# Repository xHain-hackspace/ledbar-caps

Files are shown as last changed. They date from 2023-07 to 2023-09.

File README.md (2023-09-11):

# ledbar-caps
Protective/supporting caps for creating triangle-based structures using our LED bars and rope.

For camp 2023 we wanted to build a structure using LED bars based on pipes we already have and rope running on the inside of the pipes. 3 pipes will be assembled to form  triangle and the triangles will be assembled to create shapes. For this, the ends of the pipes need a proper load bearing area and also some protection for the cables running on the outside. This repo contains 3D printable end caps which will hopefully do that job.

## Design/Test Notes
## 'cap_v4' Design
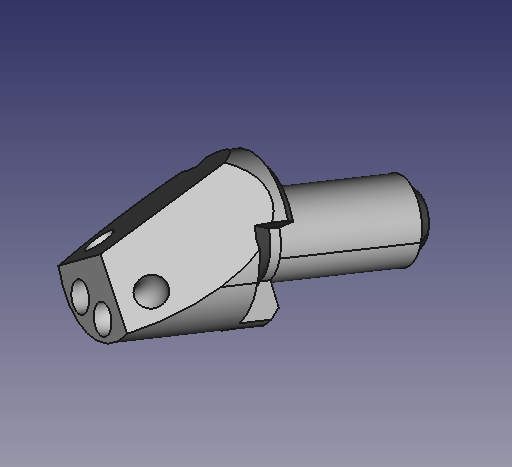
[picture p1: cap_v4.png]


  - WIP, the version we are currently testing/improving
## 'cap_v3' Design
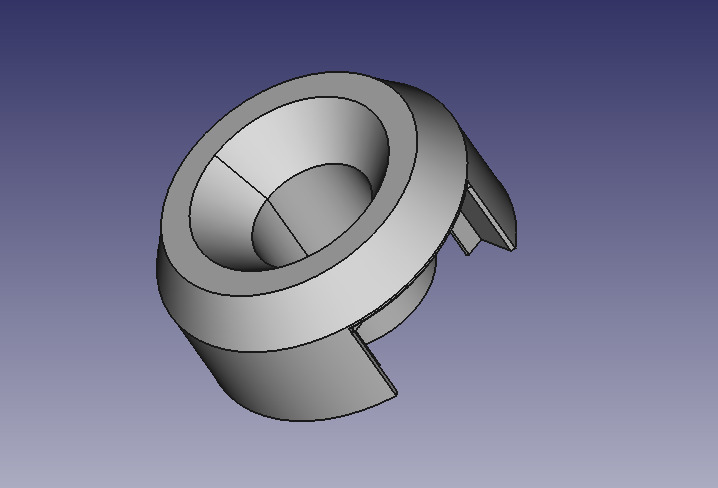
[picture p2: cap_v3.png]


  - the version we used for CCCamp in the end
  - changed top side from round to 30° edge as else the rope and the round cap create a turning moment that pulls out the caps
  - this fixes that round cap makes rope too far off pivot point, so cap wants to twist out of pipe
  - also makes everything a bit more stable (line load vs. point load)
  - threading rope works OK, a bit fiddly for multi-rope pipes
  - still kind of fiddly to set up with all the rope threading, but worked OK
  - still very sturdy with 60% infill
  - prints completely without supports
## 'cap_v2' Design
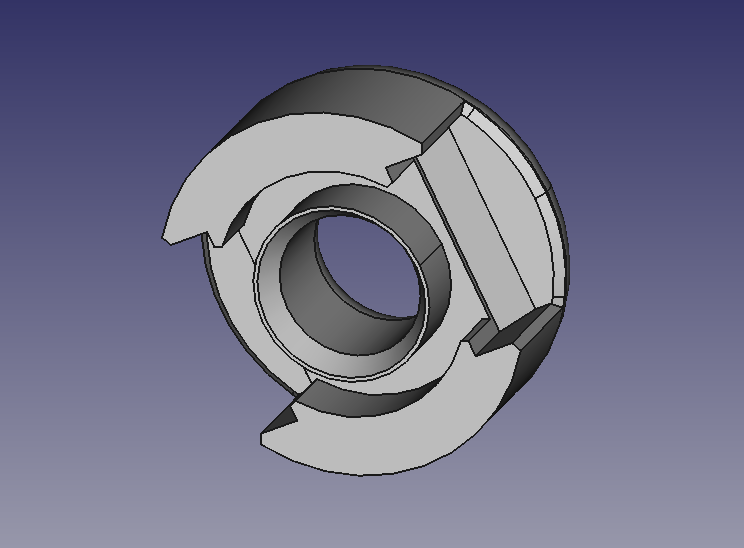
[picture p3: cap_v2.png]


  - chamfers make cap nicer and more cable friendly
  - round cap makes rope too far off pivot point, so cap wants to twist out of pipe
  - 'cap' design would probably also have this problem when tested with rope
  - inner diameter looks good
  - chamfer on inner hole makes first layer hard to print and stick for middle portion (single line circle)
  - threading rope seems to work nicely
  - still sturdy middle portion (100% infill)
## 'cap' Design
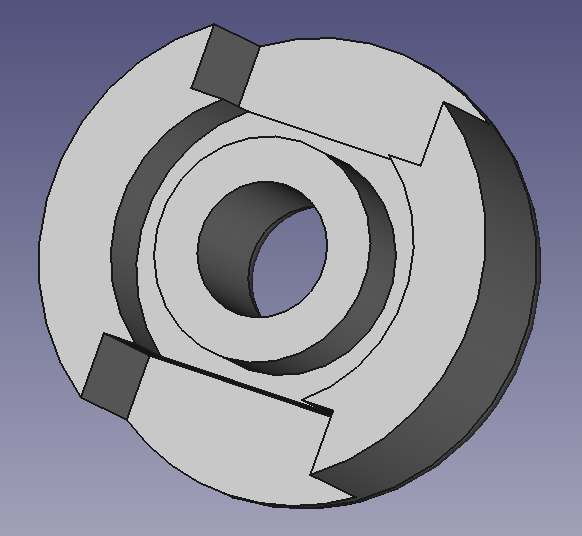
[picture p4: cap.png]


  - sits well on pipe
  - cable protection ok but, sharp edges should be chamfered
  - needs support, but we might be able to drop this
  - hole in middle needs to be bigger
  - threading rope might be difficult because of edge, might need chamfer on the inside

## 'goldcap' Design
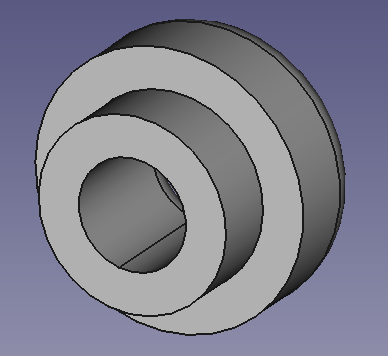
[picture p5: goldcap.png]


  - currently too small inside plug (radius/diameter mixup by accident)
  - does not really protect cables, needs to be longer
  - prints faster
  - needs support
  - hole in middle needs to be bigger
  - threading rope might be difficult because of edge, might need chamfer on the inside

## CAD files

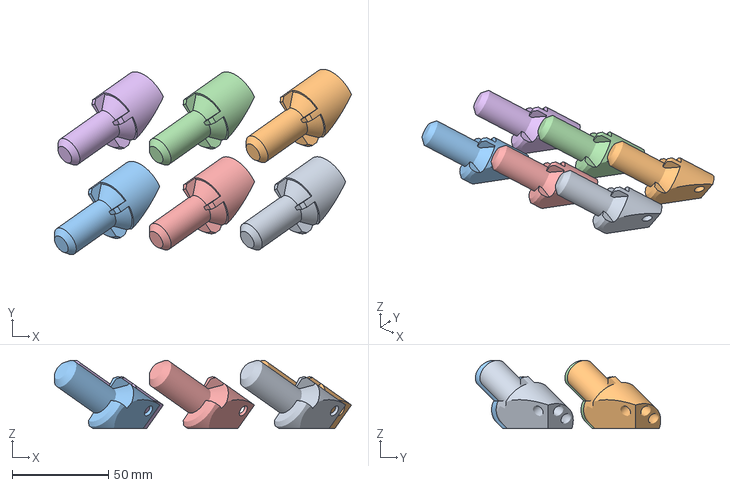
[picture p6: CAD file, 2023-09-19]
cap_v4-Body_6x_brim.3mf
154.1 x 96.2 x 35.4 mm
cap_v4-Body x 6

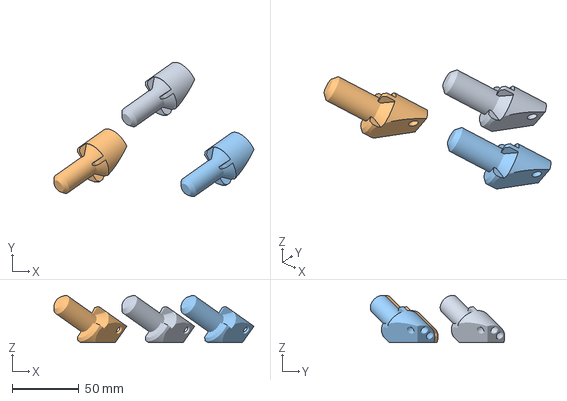
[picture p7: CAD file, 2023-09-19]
cap_v4-Body_3x_brim.3mf
150.0 x 100.9 x 35.4 mm
cap_v4-Body x 3

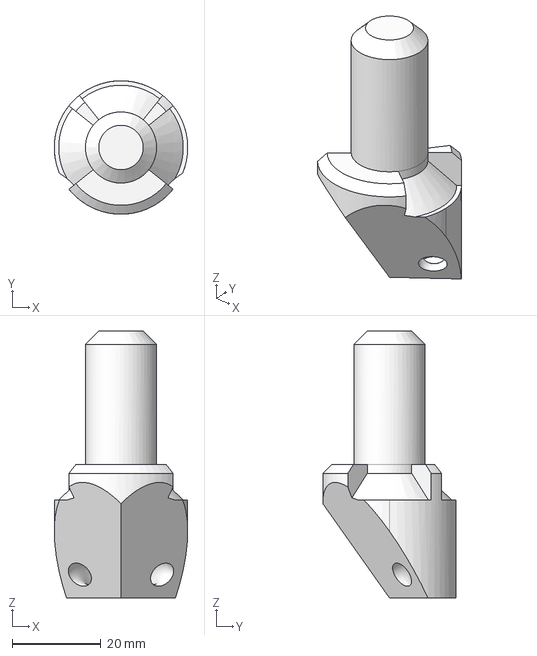
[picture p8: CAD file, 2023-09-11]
cap_v4-Body.step
30.0 x 30.0 x 60.0 mm

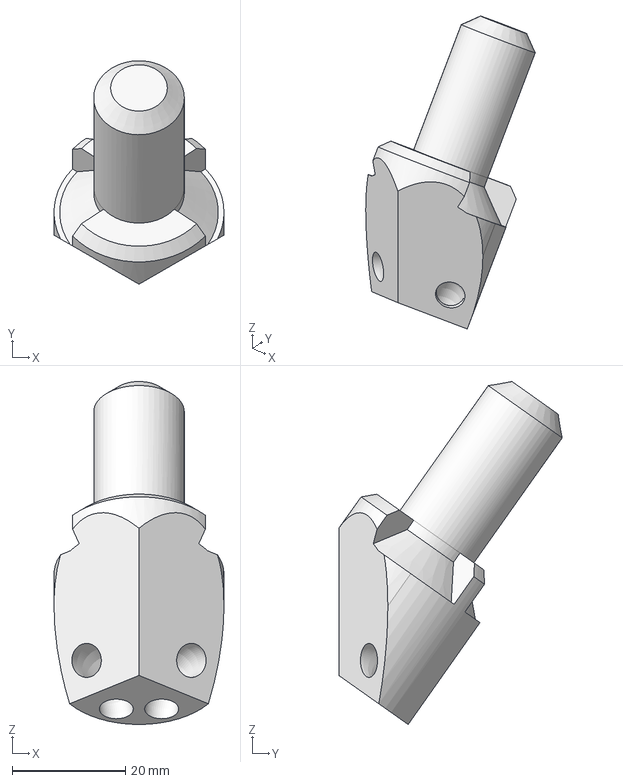
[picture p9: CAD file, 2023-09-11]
cap_v4.FCStd
30.0 x 39.4 x 60.5 mm

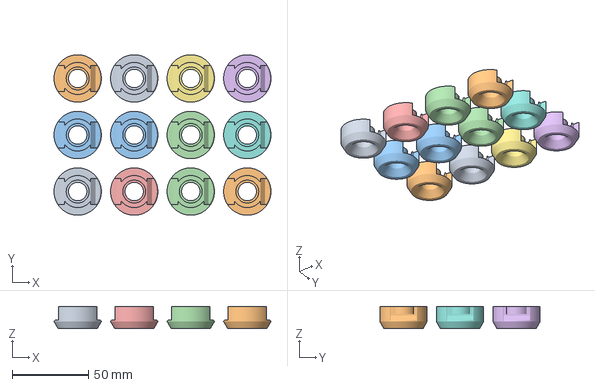
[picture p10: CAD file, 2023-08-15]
cap_v3-Body_fast_12x.3mf
142.0 x 105.0 x 14.7 mm
cap_v3-Body x 12

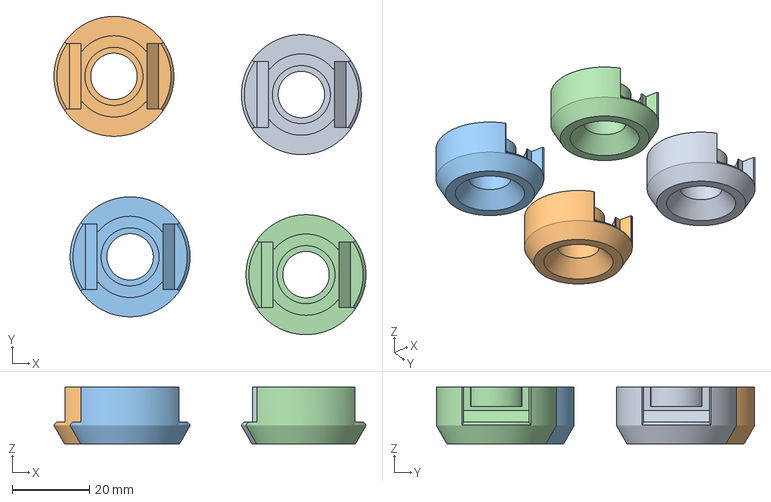
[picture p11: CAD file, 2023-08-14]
cap_v3-Body_fast_4x.3mf
80.6 x 82.3 x 14.7 mm
cap_v3-Body x 4

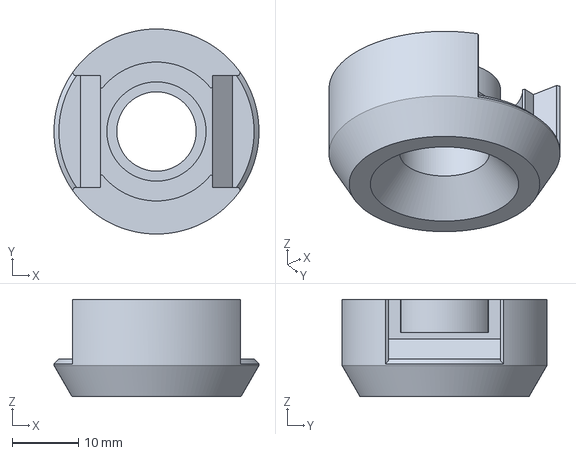
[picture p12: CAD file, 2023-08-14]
cap_v3-Body_fast.3mf
31.0 x 31.0 x 14.7 mm

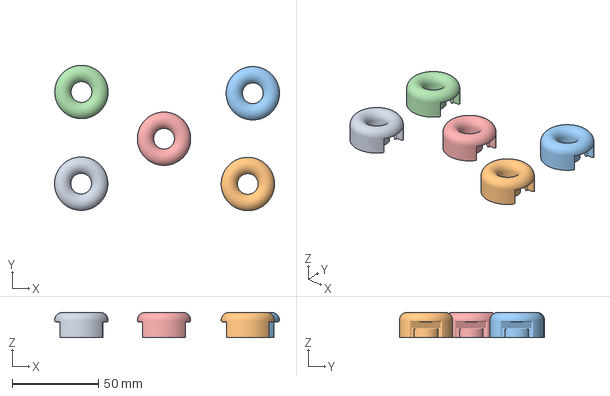
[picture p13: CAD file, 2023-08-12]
cap_v2-Body_x5.3mf
130.6 x 84.4 x 14.7 mm
cap_v2-Body x 5

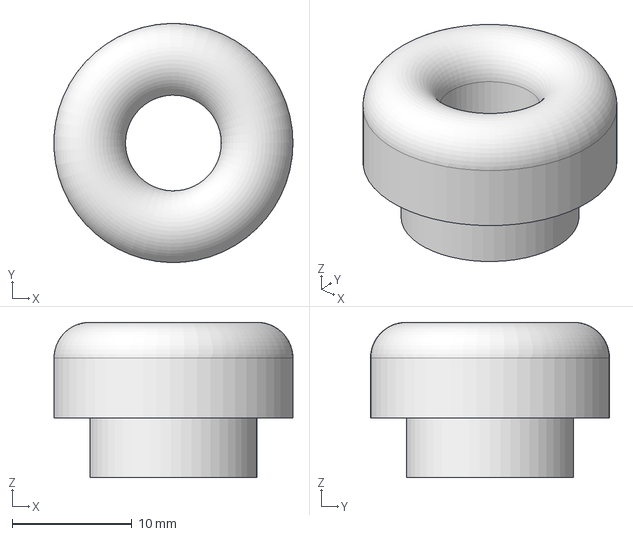
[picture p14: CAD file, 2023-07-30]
goldcap.FCStd
20.0 x 20.0 x 13.0 mm

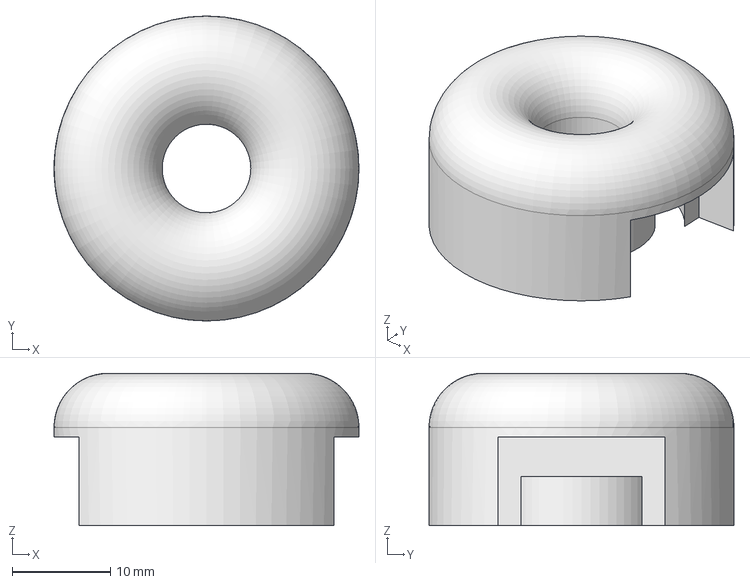
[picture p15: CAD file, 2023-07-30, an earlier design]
cap.FCStd
31.0 x 31.0 x 15.5 mm

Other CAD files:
cap_v4-Body_3x.3mf
cap_v3-Body.step
cap_v3.FCStd
cap_v2-Body.step
cap_v2.FCStd
cap_v2-Body.3mf
cap_v3-Body.3mf
cap_v4-Body.3mf

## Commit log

2023-08-12 add cap_v2
    [cap_v2-Body.3mf, cap_v2-Body.step, cap_v2-Body_x5.3mf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]
2023-08-13 add cap_v3
    [cap_v3-Body.3mf, cap_v3-Body.step, cap_v3.FCStd]
2023-08-14 faster 14 min print
    [cap_v3-Body_fast.3mf]
2023-08-14 add 4x v3 fast
    [cap_v3-Body_fast_4x.3mf]
2023-08-15 add 12x fast
    [cap_v3-Body_fast_12x.3mf]
2023-09-01 start work on v4
    [cap_v4.FCStd]
2023-09-02 add v4 first test print
    [cap_v4-Body.3mf, cap_v4-Body.step, cap_v4.FCStd]
2023-09-06 shorter rod, face hole, cable channel, 3x print
    [cap_v4-Body.3mf, cap_v4-Body.step, cap_v4.FCStd]
2023-09-11 no face hole, extend cable channel, ASA, 6 perimeter
    [cap_v4-Body.3mf, cap_v4-Body.step, cap_v4.FCStd]
2023-09-14 add 3x sliced body v4
    [cap_v4-Body_3x.3mf]
2023-09-19 add brim to 3x print
    [cap_v4-Body_3x_brim.3mf]
2023-09-19 add 6x brim gcode
    [cap_v4-Body_6x_brim.3mf]
